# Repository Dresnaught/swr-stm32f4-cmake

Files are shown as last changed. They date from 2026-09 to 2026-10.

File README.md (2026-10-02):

# Digital SWR & Power Meter

Digital SWR and RF power meter designed primarily for monitoring VHF power amplifiers / boosters (144 MHz / 2m band).

The firmware is currently running on an **STM32F401xC** ("Black Pill") for prototyping and algorithm tuning. The final target hardware is based on an **STC8H8K64U** microcontroller; schematic, 4-layer Gerber files, and PCB render images are available in `PCB and Schematic/`. All core math, calibration, menu logic, and LCD rendering are written in portable C to make porting to 8051 (SDCC / Keil C51) straightforward.

---

## Hardware & PCB Design

The custom digital controller PCB is designed around the **STC8H8K64U-45I-LQFP32** with direct 4-bit parallel LCD interface, active buzzer, optocoupler-driven relay cutoff, and TVS clamp protection on ADC inputs.

| View | With 3D Components | Without 3D Components |
| :--- | :---: | :---: |
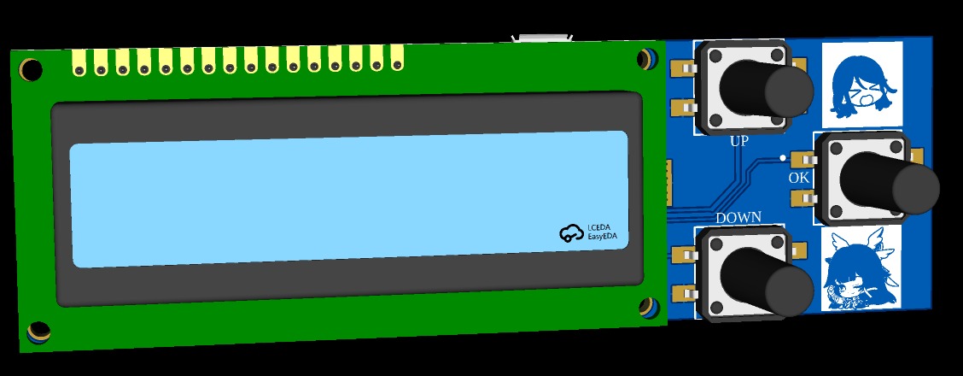
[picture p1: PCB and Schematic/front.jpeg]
PCB Front 3D
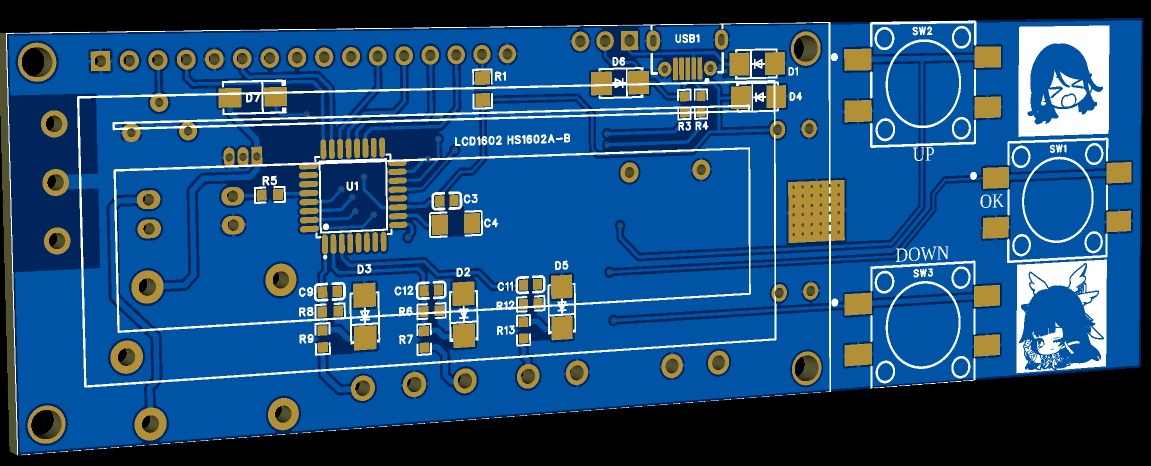
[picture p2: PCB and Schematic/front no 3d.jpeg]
PCB Front 2D
| **Front** |  |  |
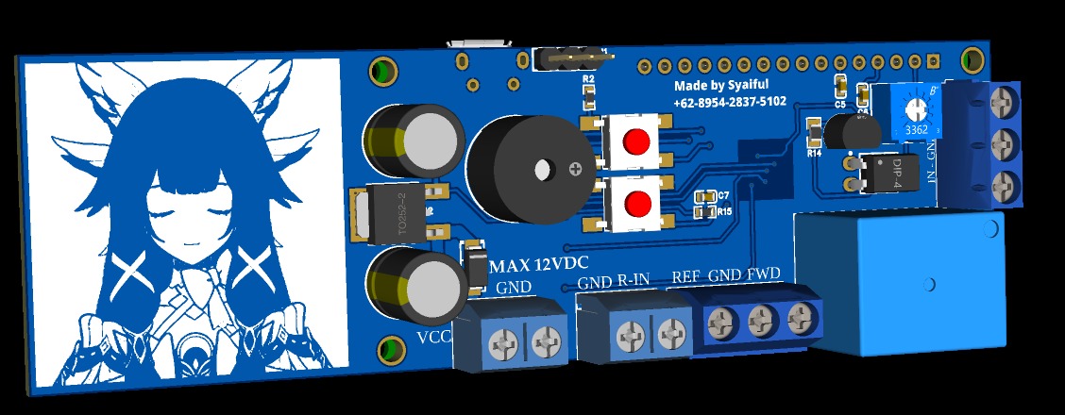
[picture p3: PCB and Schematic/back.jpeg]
PCB Back 3D
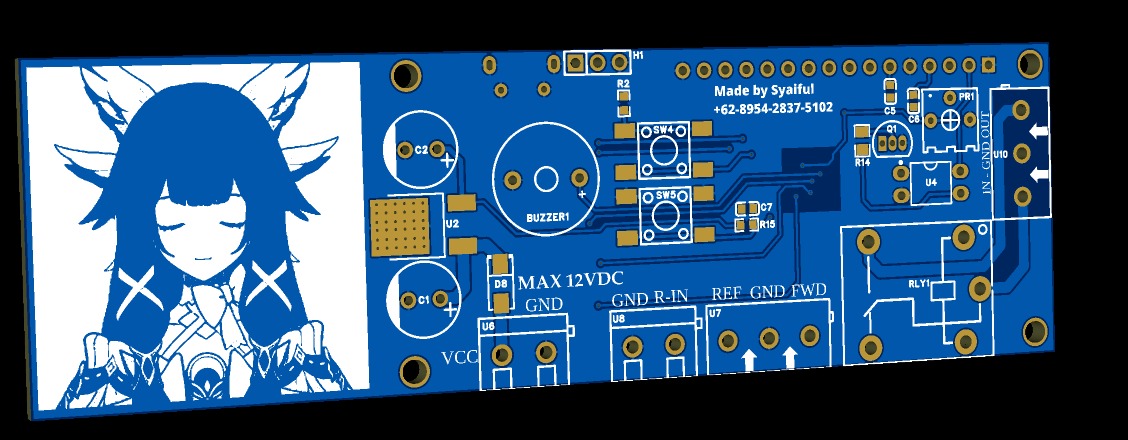
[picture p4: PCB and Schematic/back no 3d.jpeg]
PCB Back 2D
| **Back** |  |  |

> **Why is there an anime graphic on the PCB silkscreen?**  
> The reason is: *Anime*.

---

## Features

- **RF Measurements**: 3-channel 12-bit ADC sensing for Forward (`FWD`), Reflected (`REF`), and Radio Drive (`RAD`) voltages.
- **Diode Non-Linearity Compensation**: Piecewise linear interpolation (PWLI) with up to 10 user-defined calibration points per channel.
- **Proportional Curve Adaptation**: Calibrating a single known power reference (e.g. 20W) prompts `Adapt all: >YES / >NO` to proportionally scale the entire curve, preserving diode non-linearity while matching coupler sensitivity.
- **Monotonicity Protection**: Automatically detects and prevents inverted calibration points ($W_1 < W_2$ but $ADC_1 \ge ADC_2$) to prevent negative slopes or calculation bugs.
- **Auto-Marquee Scrolling**: Any LCD line exceeding 16 characters automatically scrolls smoothly (1000 ms pause, 250 ms shift per char, wrap-around) with smart frame-caching to eliminate LCD flicker.
- **Fast Integer Math**: SWR and power calculations use pure integer arithmetic and a fast integer square root (`isqrt`), keeping execution fast without floating-point overhead.
- **Signal Filtering**: Exponential moving average (EMA) filter on ADC readings to smooth out mains noise and RF jitter without introducing noticeable lag.
- **Tuned Display Refresh**: Main screen updates every 180 ms (~5.5 Hz) to match standard HD44780 LCD response times and prevent ghosting.
- **Power Bar Options**:
  - Custom tick scale (`''''|`) using 8 custom LCD CGRAM glyphs (1px ticks, half-ticks, full division marks).
  - Solid progressive bar (`|||||`).
  - Off (shows REF or RAD numeric wattage on line 2).
  - Quick toggle using UP / DOWN buttons on the home screen.
- **Hardware Protection (2-State Architecture)**:
  - High SWR cutoff (configurable from 1.1 to 5.0, only trips when FWD power is present).
  - Over-drive cutoff (RAD power limit from 1W to 50W).
  - Drives an optocoupler + relay (`PB2`) to drop transmitter PTT or insert an attenuator on fault.
  - Active buzzer alarm on trip (PB0 on proto, P2.6 on STC8).
  - **Auto-protect & non-softlock navigation**: Overload immediately cuts off the relay and switches to the trip screen (`*TRIP* HI SWR!` or `*TRIP* HI RAD!`). Pressing SELECT resets protection; holding SELECT (500ms) or UP / DOWN enters the menu without being kicked out or softlocked. Relay remains safely latched off while in the menu.
  - Manual relay test toggle in menu.
- **On-Device Calibration**:
  - Add, edit, remove, and view calibration points directly from the LCD menu.
  - Re-calibrating an existing wattage updates that point in place. Points are automatically sorted by raw ADC value.
  - Settings and calibration curves saved to Flash Sector 5 with checksum validation.
  - Unsaved change prompt on exit, plus dynamic `> Save Config` menu entry when changes are pending in RAM.
- **Standby Screen Saver**:
  - After 30 seconds of idle power (0W) without button presses, Line 2 scrolls a status marquee showing max power limits and protection status.
  - Exits immediately on any button press or RF transmission (>1W).
  - Can be toggled on/off in the menu (`> Standby Text`).
- **Hardware Watchdog with Crash Breadcrumbs**:
  - Hardware IWDG recovers automatically if RF/EMI causes CPU lockup.
  - Subsystem checkpoints stored in persistent RAM (`.noinit`) identify the exact cause upon reboot (e.g. `Why: I2C Bus Lock`, `Why: ADC Read Hang`, `Why: Manual Test`, `Why: Main Loop Stall`).
  - Notifies user on LCD at startup if reboot was caused by watchdog.
- **Hardware Diagnostics Menu**:
  - Live raw ADC monitor for FWD, REF, and RAD channels.
  - Real-time GPIO button monitor (`UP`, `SEL`, `DN`).
  - Manual relay and buzzer toggles.
  - Boot reset reason and intentional watchdog reset test.
- **Symmetrical 25ms Debounced Buttons**:
  - Industrial-grade debounce filter eliminates tactile switch chatter on both press and release.
  - Single-consumption event flags prevent double-clicks.
  - Menu transitions automatically disarm pending releases, preventing keypress bleed across screens.
  - 500 ms long hold for alternate actions.

---

## Project Status & Roadmap

| Item | Platform | Status |
| :--- | :--- | :--- |
| Core drivers (ADC, I2C, SysTick, GPIO, Buzzer) | STM32F401xC | Working |
| SWR math, PWLI interpolation, EMA filter | Portable C | Working |
| HD44780 LCD driver & custom bar characters | Portable C | Working |
| Button debouncing & long-press handling | STM32 / Portable | Working |
| Multi-point calibration, curve adapt & Flash storage | Portable C / STM32 | Working |
| Protection limits, relay cutoff & buzzer alarm | Portable C | Working |
| Display modes (Scale bar, Pipe bar, Text) | Portable C | Working |
| Standby marquee screensaver | Portable C | Working |
| Hardware IWDG watchdog with crash breadcrumbs | STM32F401xC | Working |
| Hardware diagnostic & self-test suite | Portable C | Working |
| Modular menu architecture (screen, cal, prot, diag) | Portable C | Working |
| STC8 PCB schematic, 4-layer Gerbers & 3D renders | Hardware | Complete (`PCB and Schematic/`) |
| Physical board assembly | Hardware | In progress |
| Port to STC8H8K64U | STC8 (8051) | Planned |

### Next Steps / TODO

- [ ] **RF Bench Testing with VHF Booster**: Test the prototype with a real 2m VHF booster into a dummy load. Testing will be done first on a prototype detector board without TVS diodes installed to check raw diode response and calculation linearity. Results and calibration tables will be updated after testing.
- [ ] **Protection Relay Test**: Verify trip response time during high SWR (mismatched load) and over-drive conditions under actual RF power.
- [ ] **Port to STC8H8K64U**: Once ordered parts and PCBs arrive, port the code to STC8 (using SDCC / Keil). The core math (SWR calculation, interpolation, moving average filter, menu engine, LCD bar graphics) is written in portable C to make porting straightforward.

---

## Pinout

| Signal | STM32F401 (Proto) | STC8H8K64U (Target PCB) | Description |
| :--- | :--- | :--- | :--- |
| **FWD ADC** | `PA0` (ADC1_IN0) | `P1.0` (ADC0) | Forward RF voltage via divider |
| **REF ADC** | `PA1` (ADC1_IN1) | `P1.1` (ADC1) | Reflected RF voltage via divider |
| **RAD ADC** | `PA2` (ADC1_IN2) | `P1.4` (ADC4) | Radio drive RF voltage via divider |
| **Button UP** | `PB13` (Pull-up) | `P0.1` | Up / increment / view cycle (active low) |
| **Button SELECT** | `PB14` (Pull-up) | `P0.2` | Select / confirm / hold: menu (active low) |
| **Button DOWN** | `PB15` (Pull-up) | `P0.3` | Down / decrement / view cycle (active low) |
| **Relay** | `PB2` | `P2.7` | Drives optocoupler (High = normal, Low = tripped) |
| **Buzzer** | `PB0` | `P2.6` | Buzzer on trip (alarm) |
| **I2C SCL** | `PB6` | — | LCD backpack clock (proto) |
| **I2C SDA** | `PB7` | — | LCD backpack data (proto) |
| **LCD Parallel** | — | `P2.0`–`P2.5` | 4-bit parallel bus (target PCB) |
| **Status LED** | `PC13` | — | Onboard LED heartbeat (proto) |

---

## Menu Structure

```
[ Main Screen ]
  Line 0: FWD: %4uW S:%u.%02u
  Line 1: [Scale Bar] | [Pipe Bar] | [REF / RAD text]
  UP / DOWN: Cycle display view
  SELECT: Open main menu

  ├── [ > Save Config ] (Only visible when unsaved changes exist in RAM)
  │     SEL: Write changes to flash
  │
  ├── [ > Cal FWD ] / [ > Cal REF ] / [ > Cal RAD ]
  │     ├── 1. Add Point    -> Target Watts -> Apply RF -> 5s Sample -> Adapt all? -> Save
  │     ├── 2. Edit Point   -> Pick point -> Edit Watts -> Sample -> Save
  │     ├── 3. Remove Point -> Pick point -> Confirm delete
  │     ├── 4. View Points  -> Browse saved calibration table
  │     ├── 5. Save Flash   -> Commit channel points to flash
  │     ├── 6. Reset Def    -> Restore default curves
  │     └── 7. Back         -> Return to main menu (prompts if unsaved)
  │
  ├── [ > Protections ]
  │     ├── 1. Protection ON/OFF -> Master protection toggle
  │     ├── 2. Set RAD Limit     -> 1W to 50W (or OFF)
  │     ├── 3. Set SWR Limit     -> 1.1 to 5.0 (or OFF)
  │     ├── 4. Relay Test        -> Toggle relay on/off manually
  │     ├── 5. Reset Trip        -> Clear trip condition
  │     ├── 6. Save Flash        -> Commit protection settings to flash
  │     └── 7. Back              -> Return to main menu
  │
  ├── [ > Display Mode ]
  │     ├── Power Bar Mode: OFF
  │     ├── Power Bar Mode: Custom Scale (''''|)
  │     └── Power Bar Mode: Solid Pipes (|||||)
  │           SEL: Apply mode | Hold SEL (500ms): Return to main menu
  │
  ├── [ > Standby Text ]
  │     SEL: Toggle standby screen saver ON / OFF
  │
  ├── [ > Diagnostic ]
  │     ├── 1. Live ADC     -> Real-time raw ADC monitor (FWD, REF, RAD)
  │     ├── 2. Buttons Test -> Real-time button GPIO monitor (UP, SEL, DN)
  │     ├── 3. Relay Test   -> Toggle relay state on PB2
  │     ├── 4. Buzzer Test  -> Toggle buzzer output on PB0
  │     ├── 5. Boot Reason  -> Displays reset cause & crash breadcrumb
  │     ├── 6. Watchdog Test-> Halt CPU to test watchdog reboot
  │     └── 7. Back         -> Return to main menu
  │
  └── [ > Back to Main ]
        SEL: Return to home screen
```

---

## Calculations

### Piecewise Linear Interpolation

Detector diodes are non-linear, especially at lower power levels. The code interpolates between calibrated points:

$$P = Y_0 + \frac{(ADC_{\text{raw}} - X_0) \times (Y_1 - Y_0)}{X_1 - X_0}$$

Where $(X_0, Y_0)$ and $(X_1, Y_1)$ are adjacent calibration points (raw ADC value vs actual power in Watts).

### SWR Calculation

SWR is computed from forward and reflected power using an integer square root routine without floating-point math:

$$\Gamma \times 1000 = \sqrt{\frac{P_{\text{ref}} \times 1\,000\,000}{P_{\text{fwd}}}}$$

$$\text{SWR} = \frac{1000 + (\Gamma \times 1000)}{1000 - (\Gamma \times 1000)}$$

- If $P_{\text{fwd}} \le 0$: returns 1.00 (idle).
- If $P_{\text{ref}} \ge P_{\text{fwd}}$: returns 9.99 (high SWR / open / short).
- If $P_{\text{ref}} = 0$: returns 1.00.

---

## Directory Layout

```text
swr-stm32f4-cmake/
├── CMakeLists.txt              # Build configuration
├── arm-none-eabi.cmake         # Toolchain file for ARM GCC
├── LinkerScript.ld             # Linker script for STM32F401xC (with .noinit RAM section)
├── README.md
├── LICENSE                     # PolyForm Noncommercial 1.0.0
├── PCB and Schematic/          # Target hardware files (STC8)
│   ├── SCH_Schematic1_2026-09-30.pdf # Schematic
│   ├── Gerber/                 # 4-layer production Gerbers
│   ├── front.jpeg              # 3D render (front)
│   ├── front no 3d.jpeg        # PCB layout (front)
│   ├── back.jpeg               # 3D render (back)
│   └── back no 3d.jpeg         # PCB layout (back)
└── Core/
    ├── Inc/                    # Header files
    │   ├── adc.h
    │   ├── button.h
    │   ├── buzzer.h
    │   ├── calibration.h
    │   ├── conversion.h
    │   ├── lcd.h
    │   ├── menu.h
    │   ├── menu_calibration.h
    │   ├── menu_diagnostic.h
    │   ├── menu_main_screen.h
    │   ├── menu_protection.h
    │   ├── protection.h
    │   ├── storage.h
    │   ├── sytick.h
    │   └── watchdog.h
    └── Src/                    # Implementation
        ├── adc.c               # ADC1 register-level driver
        ├── button.c            # Debounced button inputs & hold detection
        ├── buzzer.c            # Buzzer driver (PB0 on proto, P2.6 on STC8)
        ├── calibration.c       # Calibration CRUD, sorting, and curve scaling
        ├── conversion.c        # SWR integer math & EMA filter
        ├── lcd.c               # I2C LCD driver & custom glyphs
        ├── main.c              # Entry point, watchdog tracking & main loop
        ├── menu.c              # Main menu coordinator & LCD helpers
        ├── menu_calibration.c  # Multi-point calibration & adapt workflow
        ├── menu_diagnostic.c   # Hardware diagnostic & self-test routines
        ├── menu_main_screen.c  # Home measurement screen & power bars
        ├── menu_protection.c   # Protection thresholds & relay controls
        ├── protection.c        # Protection trip engine & relay control
        ├── storage_stm32.c     # Flash Sector 5 persistence
        ├── sytick.c            # Delay functions
        ├── watchdog.c          # IWDG driver & .noinit crash breadcrumbs
        ├── startup_stm32f401xc.s
        └── system_stm32f4xx.c
```

---

## Building and Flashing

### Requirements
- `arm-none-eabi-gcc` toolchain
- CMake (>= 3.20) and Ninja (or Make)
- `stlink-tools` (`st-flash`) or OpenOCD

### Build
```bash
cmake -B build -G Ninja -DCMAKE_TOOLCHAIN_FILE=arm-none-eabi.cmake
cmake --build build
```

### Flash
```bash
cmake --build build --target flash
# or using st-flash directly:
st-flash --reset write build/swr-stm32f4-cmake.bin 0x08000000
```

---

## License

This project is licensed under the [PolyForm Noncommercial License 1.0.0](LICENSE). Free for personal, hobbyist, and educational use. Commercial use is not permitted without permission.

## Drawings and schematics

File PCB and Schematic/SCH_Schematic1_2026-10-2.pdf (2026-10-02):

# ADC READ IN

# POWER IN PSU

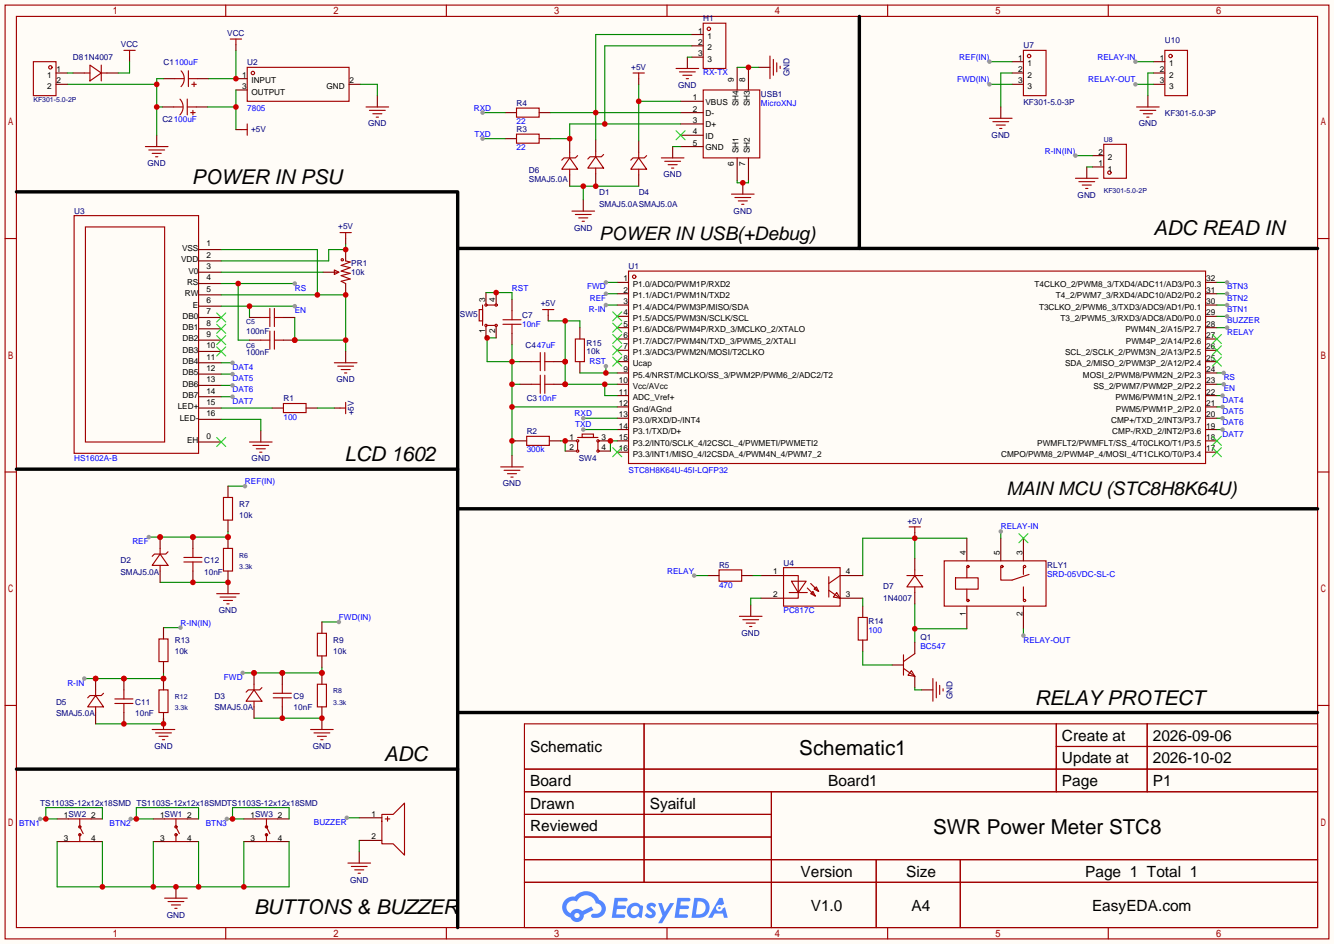
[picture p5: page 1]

Schematic | Schematic1 | Create at | 2026-09-06

Update at | 2026-10-02

Board | Board1 | Page | P1
Drawn | Syaiful | SWR Power Meter STC8
Reviewed

Version | Size | Page 1 Total 1
V1.0 | A4 | EasyEDA.com

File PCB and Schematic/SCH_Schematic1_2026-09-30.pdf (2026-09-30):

# ADC READ IN

# POWER IN PSU

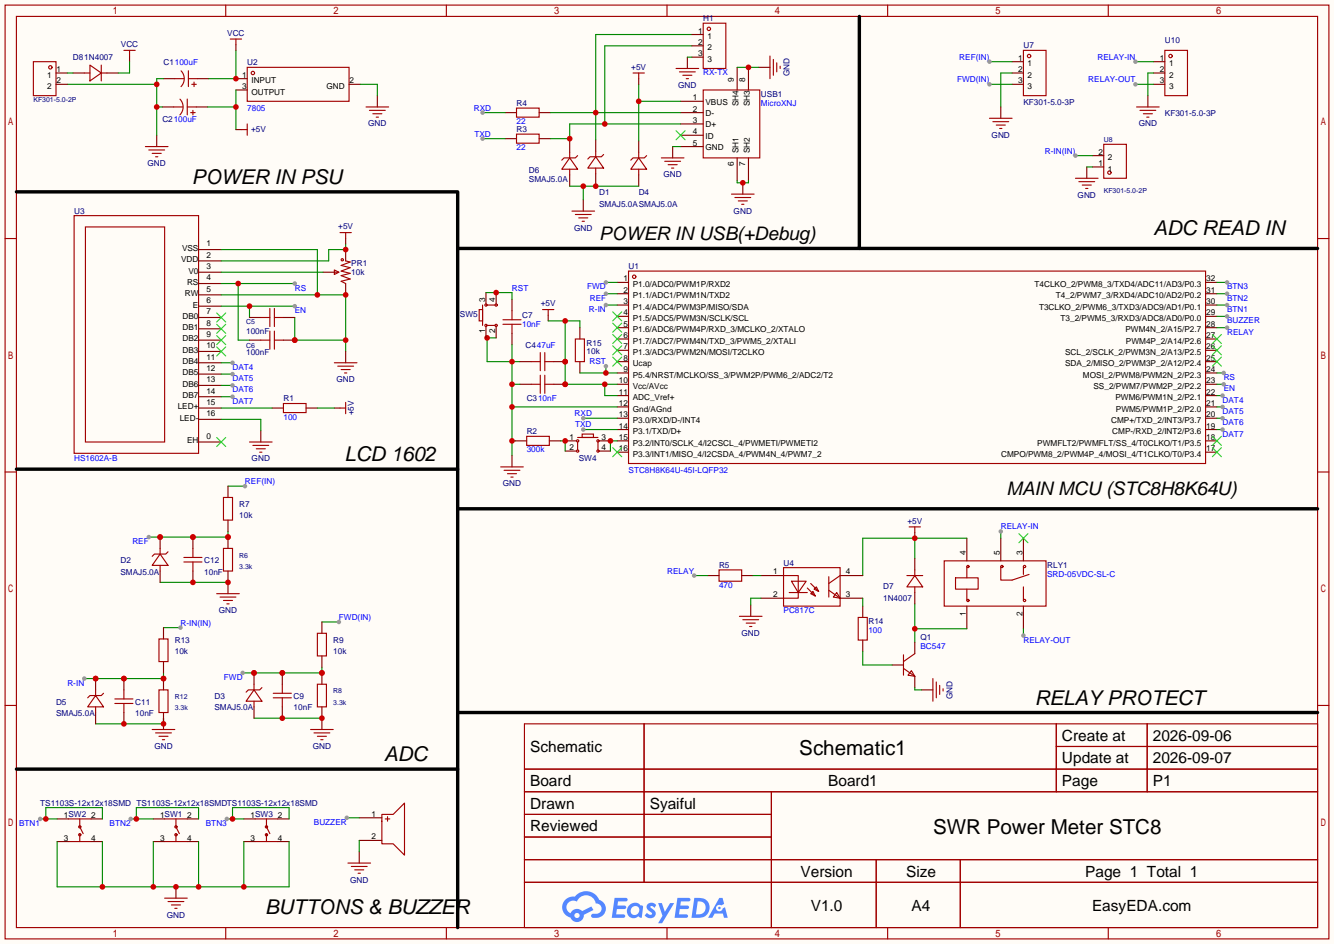
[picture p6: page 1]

Schematic | Schematic1 | Create at | 2026-09-06

Update at | 2026-09-07

Board | Board1 | Page | P1
Drawn | Syaiful | SWR Power Meter STC8
Reviewed

Version | Size | Page 1 Total 1
V1.0 | A4 | EasyEDA.com

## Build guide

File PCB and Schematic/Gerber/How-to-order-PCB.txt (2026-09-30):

How to Order PCB

Please refer to:
https://prodocs.easyeda.com/en/pcb/order-order-pcb/index.html

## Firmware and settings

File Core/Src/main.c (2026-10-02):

#include "lcd.h"
#include "adc.h"
#include "conversion.h"
#include "calibration.h"
#include "protection.h"
#include "button.h"
#include "menu.h"
#include "menu_main_screen.h"
#include "stm32f401xc.h"
#include "sytick.h"
#include "watchdog.h"
#include "buzzer.h"
#include <stdio.h>
#include <stdint.h>
#include <stdbool.h>

int main(void) {
  // Check RCC reset flags and crash breadcrumb before clearing
  watchdogCheckResetReason();

  timeInit();
  I2C1Init();
  lcd_init();
  buttonInit();
  buzzerInit();
  ADCInit();
  calInit(); // Load calibration & protection settings from Flash
  protectionInit(); // Initialize protection relay / optocoupler pin (PB2)
  updateRunningText(); // Pre-populate running marquee buffer

  // Configure PC13 (Status LED on BlackPill) as output
  RCC->AHB1ENR |= RCC_AHB1ENR_GPIOCEN;
  GPIOC->MODER &= ~(0x3 << (13 * 2));
  GPIOC->MODER |= (0x1 << (13 * 2));

  // If rebooted by watchdog, show the specific crash reason
  if (watchdogWasResetByIWDG()) {
    char reasonBuf[17];
    snprintf(reasonBuf, sizeof(reasonBuf), "Why: %-11s", watchdogGetCrashReasonStr());
    lcdCursor(0, 0);
    lcdString("*WATCHDOG RESET*");
    lcdCursor(1, 0);
    lcdString(reasonBuf);
    buzzerBeep(150);

    // Wait up to 2.5s or until user presses any button
    for (int i = 0; i < 25; i++) {
      buzzerUpdate();
      delay_ms(100);
      if (buttonJustPressed(13) || buttonJustPressed(14) || buttonJustPressed(15)) {
        break;
      }
    }
  } else {
    lcdCursor(0, 0);
    lcdString("SWR Power Meter ");
    lcdCursor(1, 0);
    lcdString("Digital STC8/F4 ");
    delay_ms(900);
  }

  // Initialize independent watchdog for crash and RF lockup recovery
  watchdogInit();

  while (1) {
    watchdogSetLocation(WDG_LOC_MAIN_LOOP);
    watchdogRefresh();
    buzzerUpdate();
    buttonUpdate();

    watchdogSetLocation(WDG_LOC_ADC_READ);
    readReading();

    watchdogSetLocation(WDG_LOC_MAIN_LOOP);
    protectionCheck(calibratedFWD, calibratedRAD, calculatedSWRValue);

    if (updateReadings()) {
      watchdogSetLocation(WDG_LOC_LCD_I2C);
      displayMenu(currentMenu);
    }
  }
}

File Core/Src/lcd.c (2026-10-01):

#include "lcd.h"
#include "stm32f401xc.h"
#include "sytick.h" // for delay_ms

// I2C1 initialization function
void I2C1Init(void) {
  RCC->AHB1ENR |= RCC_AHB1ENR_GPIOBEN;
  RCC->APB1ENR |= RCC_APB1ENR_I2C1EN;
  GPIOB->MODER &= ~(0xFU << (6 * 2));
  GPIOB->MODER |= (0xAU << (6 * 2));
  GPIOB->OSPEEDR |= (0xFU << (6 * 2));
  GPIOB->OTYPER |= (0x3U << 6);
  GPIOB->PUPDR &= ~(0xFU << (6 * 2));
  GPIOB->AFR[0] &= ~(0xFFU << GPIO_AFRL_AFSEL6_Pos);
  GPIOB->AFR[0] |= (0x44U << GPIO_AFRL_AFSEL6_Pos);
  I2C1->CR1 |= I2C_CR1_SWRST;
  I2C1->CR1 &= ~I2C_CR1_SWRST;

  I2C1->CR2 &= ~I2C_CR2_FREQ; // Clear FREQ bits
  I2C1->CR2 |= 16;            // 16 MHz

  // Configure Clock Control Register (CCR) for 100 kHz Standard Mode
  // Thigh = Tlow = 5000ns (for 100 kHz)
  // CCR = PCLK1 / (2 * I2C_Speed) -> 16,000,000 / (2 * 100,000) = 80
  I2C1->CCR &= ~I2C_CCR_FS;  // 0: Standard Mode
  I2C1->CCR &= ~I2C_CCR_CCR; // Clear CCR bits
  I2C1->CCR |= 80;           // Set CCR to 80

  // Configure Maximum Rise Time (TRISE)
  // In Standard Mode, max rise time is 1000ns.
  // TRISE = (Max_Rise_Time / T_PCLK1) + 1 -> (1000ns / 62.5ns) + 1 = 16 + 1 =
  // 17
  I2C1->TRISE = 17;

  // Enable I2C1 Peripheral
  I2C1->CR1 |= I2C_CR1_PE;
}

uint8_t I2C1_Master_Transmit(uint8_t slave_addr, uint8_t *data, uint8_t size) {
  // 1. Generate START condition
  I2C1->CR1 |= I2C_CR1_START;
  while (!(I2C1->SR1 & I2C_SR1_SB))
    ;

  // 2. Send Slave Address (shifted left by 1, with LSB = 0 for Write)
  I2C1->DR = (slave_addr << 1);
  while (!(I2C1->SR1 & I2C_SR1_ADDR))
    ;

  // Clear ADDR flag sequence
  volatile uint32_t temp = I2C1->SR1;
  temp = I2C1->SR2;
  (void)temp;

  // 3. Transmit Data Sequence
  for (uint8_t i = 0; i < size; i++) {
    while (!(I2C1->SR1 & I2C_SR1_TXE))
      ;
    I2C1->DR = data[i];
  }

  // Wait for the final byte to leave the shift register
  while (!(I2C1->SR1 & I2C_SR1_BTF))
    ;

  // 4. Generate STOP condition
  I2C1->CR1 |= I2C_CR1_STOP;

  return 0;
}

void lcd_send_cmd(char cmd) {
  char data_u = (cmd & 0xF0);
  char data_l = ((cmd << 4) & 0xF0);
  uint8_t d[1];

  // Upper Nibble
  d[0] = data_u | 0x0C;
  I2C1_Master_Transmit(LCD_ADDRESS, d, 1); // EN=1, RS=0
  delay_us(2);                             // Let data settle
  d[0] = data_u | 0x08;
  I2C1_Master_Transmit(LCD_ADDRESS, d, 1); // EN=0, RS=0
  delay_us(2);

  // Lower Nibble
  d[0] = data_l | 0x0C;
  I2C1_Master_Transmit(LCD_ADDRESS, d, 1); // EN=1, RS=0
  delay_us(2);
  d[0] = data_l | 0x08;
  I2C1_Master_Transmit(LCD_ADDRESS, d, 1); // EN=0, RS=0
  delay_us(40); // Standard command execution wait time
}

void lcd_send_data(char data) {
  char data_u = (data & 0xF0);
  char data_l = ((data << 4) & 0xF0);
  uint8_t d[1];

  // Upper Nibble
  d[0] = data_u | 0x0D;
  I2C1_Master_Transmit(LCD_ADDRESS, d, 1); // EN=1, RS=1
  delay_us(2);
  d[0] = data_u | 0x09;
  I2C1_Master_Transmit(LCD_ADDRESS, d, 1); // EN=0, RS=1
  delay_us(2);

  // Lower Nibble
  d[0] = data_l | 0x0D;
  I2C1_Master_Transmit(LCD_ADDRESS, d, 1); // EN=1, RS=1
  delay_us(2);
  d[0] = data_l | 0x09;
  I2C1_Master_Transmit(LCD_ADDRESS, d, 1); // EN=0, RS=1
  delay_us(40);
}

void lcd_send_nibble(char nibble) {
  uint8_t d[1];
  d[0] = (nibble & 0xF0) | 0x0C; // EN=1, RS=0
  I2C1_Master_Transmit(LCD_ADDRESS, d, 1);
  delay_us(2);
  d[0] = (nibble & 0xF0) | 0x08; // EN=0, RS=0
  I2C1_Master_Transmit(LCD_ADDRESS, d, 1);
  delay_us(40);
}

void lcd_init(void) {
  delay_ms(50);

  // Force 8-bit mode 3 times to sync up state machines
  lcd_send_nibble(0x30);
  delay_ms(5);
  lcd_send_nibble(0x30);
  delay_us(150);
  lcd_send_nibble(0x30);
  delay_ms(10);

  // Set to 4-bit mode configuration
  lcd_send_nibble(0x20);
  delay_ms(10);
  lcd_send_cmd(0x28); // 4-bit, 2-line, 5×8 font
  delay_ms(1);
  lcd_send_cmd(0x08); // display OFF
  delay_ms(1);
  lcd_send_cmd(0x01); // clear display
  delay_ms(2);
  lcd_send_cmd(0x06); // entry mode
  delay_ms(1);
  lcd_send_cmd(0x0C); // display ON, cursor OFF
  delay_ms(1);

  lcdInitCustomChars();
}

void lcdCreateChar(uint8_t location, const uint8_t charmap[8]) {
  location &= 0x07;
  lcd_send_cmd(0x40 | (location << 3));
  for (int i = 0; i < 8; i++) {
    lcd_send_data(charmap[i]);
  }
}

void lcdInitCustomChars(void) {
  // 0: Initial tip character for scale bar (centered full line)
  static const uint8_t char_tip_init[8] = {
    0x04, 0x04, 0x04, 0x04, 0x04, 0x04, 0x04, 0x04
  };

  // 1: 1 vertical line (column 0)
  static const uint8_t char_1_line[8] = {
    0x10, 0x10, 0x10, 0x10, 0x10, 0x10, 0x10, 0x10
  };

  // 2: 2 vertical lines (columns 0, 1)
  static const uint8_t char_2_lines[8] = {
    0x18, 0x18, 0x18, 0x18, 0x18, 0x18, 0x18, 0x18
  };

  // 3: 3 vertical lines (columns 0, 1, 2)
  static const uint8_t char_3_lines[8] = {
    0x1C, 0x1C, 0x1C, 0x1C, 0x1C, 0x1C, 0x1C, 0x1C
  };

  // 4: 4 vertical lines (columns 0, 1, 2, 3)
  static const uint8_t char_4_lines[8] = {
    0x1E, 0x1E, 0x1E, 0x1E, 0x1E, 0x1E, 0x1E, 0x1E
  };

  // 5: 5 vertical lines (columns 0, 1, 2, 3, 4: |||||)
  static const uint8_t char_5_lines[8] = {
    0x1F, 0x1F, 0x1F, 0x1F, 0x1F, 0x1F, 0x1F, 0x1F
  };

  // 6: Scale Even Cell (ticks at 1, 3 with 1-pixel uniform spacing)
  static const uint8_t char_scale_even[8] = {
    0x0A, 0x0A, 0x00, 0x00, 0x00, 0x00, 0x00, 0x00
  };

  // 7: Scale Odd Cell (ticks at 0, 2; half-line at 4 with 1-pixel uniform spacing)
  static const uint8_t char_scale_odd[8] = {
    0x15, 0x15, 0x01, 0x01, 0x01, 0x00, 0x00, 0x00
  };

  lcdCreateChar(0, char_tip_init);
  lcdCreateChar(1, char_1_line);
  lcdCreateChar(2, char_2_lines);
  lcdCreateChar(3, char_3_lines);
  lcdCreateChar(4, char_4_lines);
  lcdCreateChar(5, char_5_lines);
  lcdCreateChar(6, char_scale_even);
  lcdCreateChar(7, char_scale_odd);

  // Return LCD to DDRAM mode
  lcdCursor(0, 0);
}

void lcdCursor(int row, int col) {
  switch (row) {
  case 0:
    col |= 0x80;
    break; // DDRAM row 0 starts at 0x00
  case 1:
    col |= 0xC0;
    break; // DDRAM row 1 starts at 0x40
  }
  lcd_send_cmd(col);
}

void lcdString(char *str) {
  while (*str)
    lcd_send_data(*str++);
}

void lcdInt(int num) {
  char buf[12];
  int i = 0;

  if (num == 0) {
    lcdString("0");
    return;
  }

  int isNegative = 0;
  long long n = num;
  if (n < 0) {
    isNegative = 1;
    n = -n;
  }

  while (n > 0) {
    buf[i++] = (n % 10) + '0';
    n /= 10;
  }

  if (isNegative) {
    buf[i++] = '-';
  }

  for (int j = i - 1; j >= 0; j--) {
  }

  char reversed[13];
  int r = 0;
  for (int j = i - 1; j >= 0; j--) {
    reversed[r++] = buf[j];
  }
  reversed[r] = '\0';

  lcdString(reversed);
}
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

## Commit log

2026-09-29 Fix the issue with CMake configuration for the ARM toolchain make systick modular, while add lcd driver
    [lcd.c, main.c]
2026-09-29 Added menu logic, and button logic. to do next commit: calibration interpolation, calibration storage, and menu navigation to calibration. havent tested the menu yet, but the logics should be fine. I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
2026-09-30 update readme and added gerber files for pcb and schematic
    [Drill_PTH_Through.DRL, Drill_PTH_Through_Via.DRL, Gerber_BoardOutlineLayer.GKO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]
2026-09-30 added calibration logic not tested yet
2026-10-01 fixed bugs and issues and tested the functionality of the system added new features to the system that is: improved button handling and response time improved ADC conversion accuracy and stability im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
    [adc.c, button.c, conversion.c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]
2026-10-02 added features. buzzer,improved calibration, menu and diagnostic watchdog improvements.
    [buzzer.c, main.c, protection.c]
2026-10-02 improve menu file as modular, and update gerber pcb.
    [Drill_PTH_Through.DRL, Drill_PTH_Through_Via.DRL, Gerber_BoardOutlineLayer.GKO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]
2026-10-02 improve button handling; and fix some issues in menu and protection modules
    [button.c, main.c, menu_calibration.c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]
2026-10-02 Modify PCB layout options in README
    Updated the README to reflect changes in PCB layout options.
